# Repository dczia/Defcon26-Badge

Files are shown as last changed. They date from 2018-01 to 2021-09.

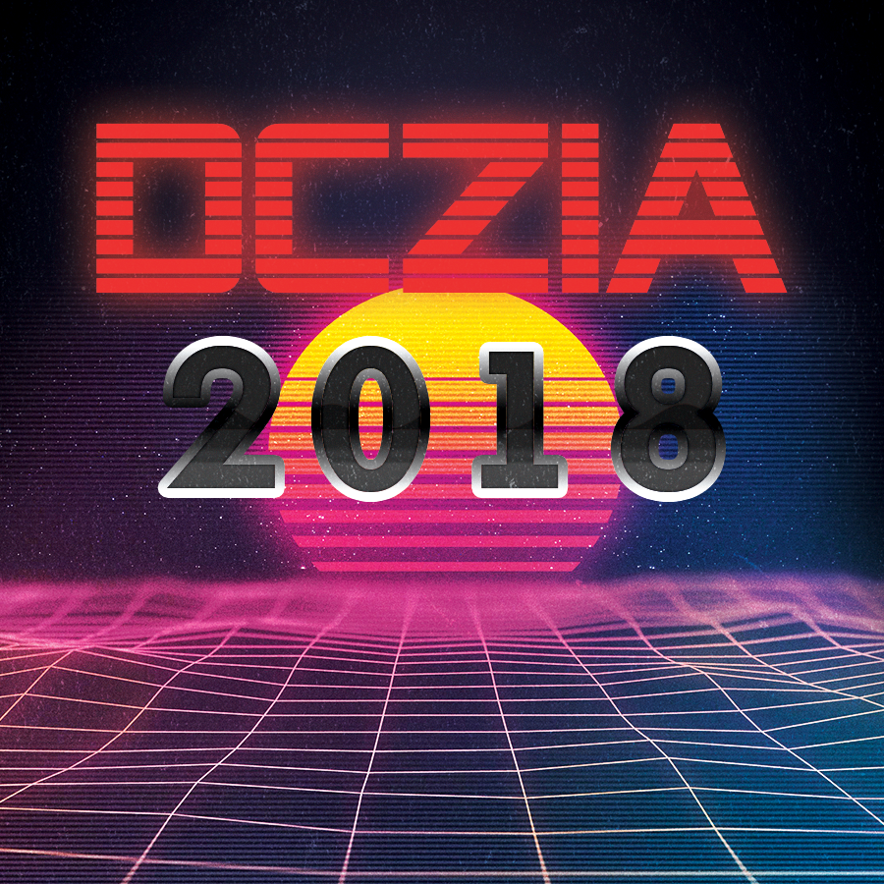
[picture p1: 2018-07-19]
Images/DCZia Sticker 3.png

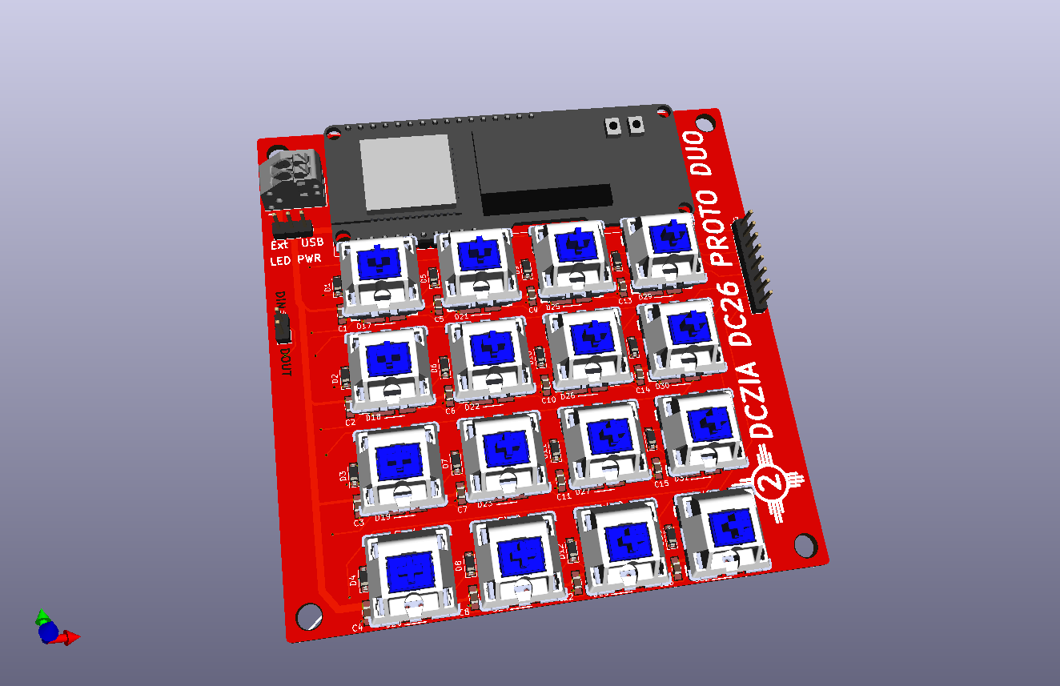
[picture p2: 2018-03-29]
Hardware/KeyGridBadge/images/Generated/KeyGridTest2_Front.png

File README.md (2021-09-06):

# ＤＣＺＩＡ ２０１８

```
 ___   ___ _____        ___ __  _ ___
|   \ / __|_  (_)__ _  |_  )  \/ ( _ )
| |) | (__ / /| / _` |  / / () | / _ \
|___/ \___/___|_\__,_| /___\__/|_\___/

 _________
| DCZ ■■ ⧻|
| □ □ □ □ |
| □ □ □ □ |
| □ □ □ □ |
|_□_□_□_□_|

```
**News**
September 2021
* Added new pre built binary file of the badge firmware with bug fixes for the boot loop issue. (Thanks to Aask for the guidance!)
* Updated final software readme and this readme.

August 2018
* FINAL INO is up use that for use with the final board.  
* ProtoDos is frozen for now. Library changes + board layout changes mean Final and Dos aren't really interchangable.

July 2018 Update 2
* ProtoDos code updated with BLE Code working and advertising to DC26 with 0X5050 Manufacturing ID
* Some ProtoDos code cleanup 

June 2018 Update
* Final board revision in the works. Expecting proto tres boards soon.
* Possibly switching OLED Libraries to U8G2 (https://github.com/olikraus/u8g2)
* Screen will likely be a 0.91" 128x32pixel OLED ala https://www.aliexpress.com/item/0-91-Inch-128x32-IIC-I2C-Blue-OLED-LCD-Display-DIY-Module-SSD1306-Driver-IC-DC/32793415973.html
	
May 2018  Update
* Proto Tres Board revision has begun.
* Please write down your ideas for lighting / BLE in the Google Doc for badge development.

March 2018 Update
* Proto Dos boards are in, working, and off to Lithochasm for redistribution with the keys

Feb 2018 Update
* Dev boards have been made by Hamster. He identified an issue with the footprint of the leds, and is working on a fix.
* Clear keycaps have begun printing by Litho. Switches and LED's for a dev board test have been ordered as well.
* Software developemt has not begun. 
* Goals for Feb, get dev boards up and in the hands of folks. 
* Ideas for software features
* Laynard Design

**What is the DCZia 2018 Badge**

This year we want to keep up with the tradition of our past badge which contained mechanical keyswitches on it to give it a retro look and feel. We decided on a 4x4 grid of mechanical keyswitches with an rgb led underneath and transparent keycaps to make an interactive display of sorts.

We also will be adding a small oled at the top center of the badge for more ovbious visual output. Board will be powered by an ESP32 and will talk BTLE and possibly Wi-Fi if we can find something cool to do with it.

Defcon2018 Style Guide: https://defcon.org/html/defcon-26/dc-26-theme.html

**Technical Notes**
* ESP32 Microcontroller
* SSD1306 OLED Screen
* Gatreon Blue Keyswitches
* Neopixel Mini RGB LEDs
* 3x AA power or USB power
* Shitty / Minibadge Addons supported

**DevKit Setup Instructions**

- Follow the [ESP32 Setup Instructions](https://github.com/espressif/arduino-esp32#installation-instructions) to get the latest board version. (NOTE: This is required to use BLE as there are recent updates)
- Compile and upload to your Proto-Dos board
- Enjoy all the fun menu settings, light show and BLE experience. 

To Test: 
- Use Nordic's nRF utility for the phone. 
- Review #badgelife's doc for BLE communication.  Compare to last year's badge to see the correct manufacturer ID and appearance.

#dczia

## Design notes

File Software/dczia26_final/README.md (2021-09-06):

# dczia26_final

This is it.

## Overview
DC Zia 26 - 2018 Final Build Out.
This should cover what is required for building and loading the sketch onto the DC Zia badge.
You can build the firmware using the arduino .ino sketch, or we now have a binay file that can be uploaded using something like esptool (https://diyprojects.io/esp-easy-flash-firmware-esptool-py-esp8266/)

### Required Libraries
- Espressif ESP32 - [ESP32 Setup Instructions](https://github.com/espressif/arduino-esp32#installation-instructions)
- NeopixelBus
- arduinoFFT
- Adafruit SSD1306 OLED Library
- Adafruit GDX Library
- Neopixel BUS Library
- Keypad (http://playground.arduino.cc/Code/Keypad)

### Build Instructions
Make sure you're running a recent version of Arduino Studio. 
Follow the instructions for installing the Espressif ESP32 boards via the board manager at ([ESP32 Setup Instructions](https://github.com/espressif/arduino-esp32#installation-instructions)).

Open `dczia_final.ino` in Arduino Studio.
Select the correct board:
  - TOOLS -> Board -> ESP 32 Dev Module
Select the connected COM port (should be autodetected).
Compile the sketch using the checkmark.
Upload the sketch to the board.
Enjoy the lightshow.

### Usage of the Badge
The Board will boot into a default light mode. Press and hold the bottom right key to exit the current mode and goto the main menu.
The top 9 buttons each will activate a different mode.
Press and hold the bottom right key to exit the current mode.

### Troubleshooting
- Fails to compile
  - Double check that Espressif ESP32 is installed correctly
  - Review all required libraries and make sure they're installed
  - Review errors to identify if it is a board issue vs a library issue.
- Fails to upload
  - Double check to make sure Espressif python tools were fully configured.
  - Make sure the badge is connected and on (reconnect with badge switched to ON without batteries)
- Display issues
  - Make sure you're using Adafruit libraries and it is configured for `128x32`

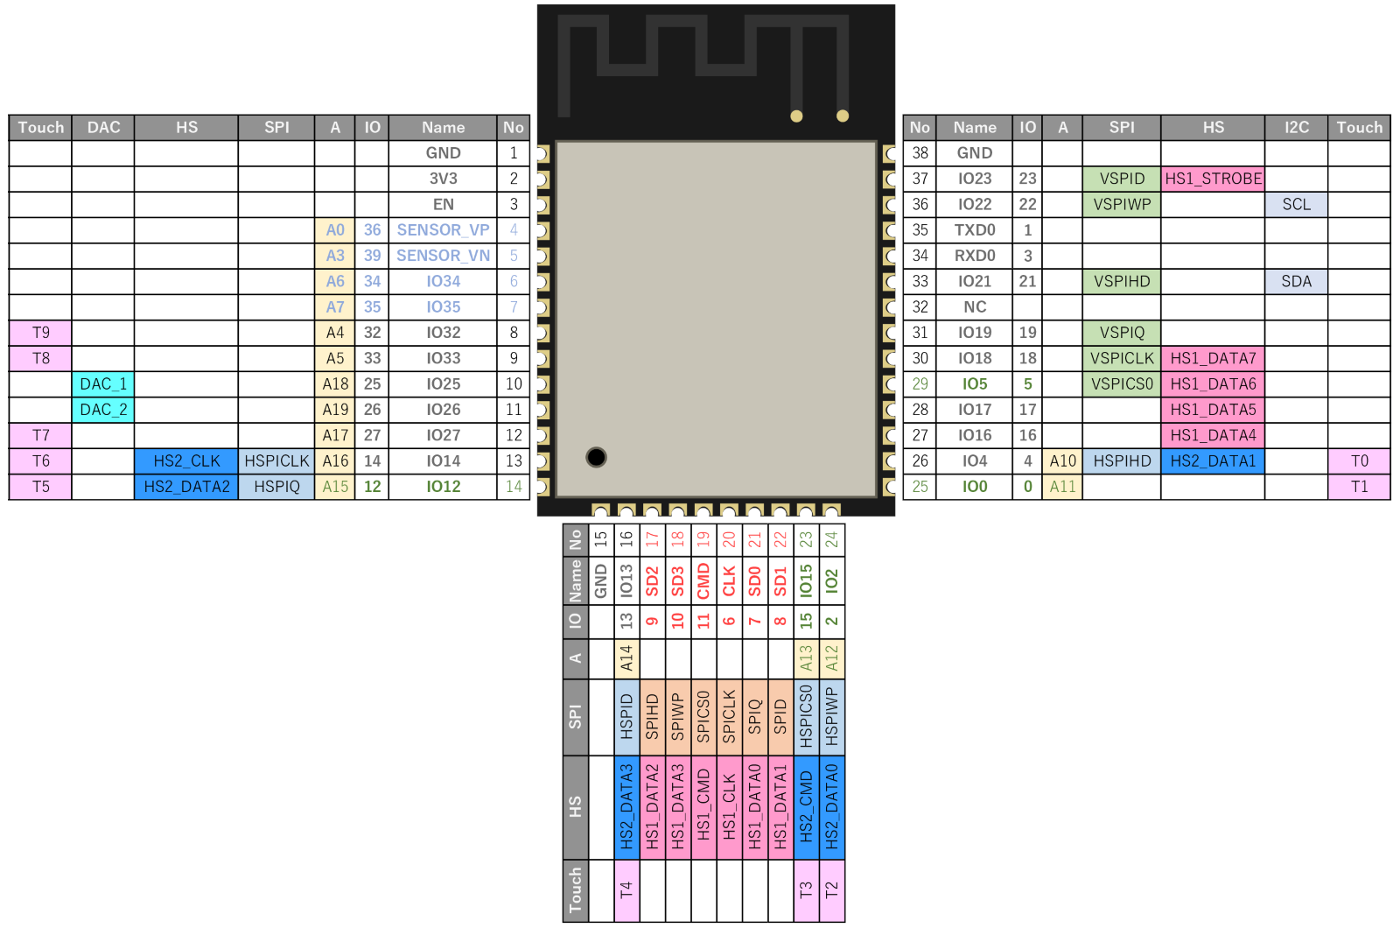
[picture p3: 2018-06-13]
Hardware/esp32_info/esp-wroom-32_pinout_01.png

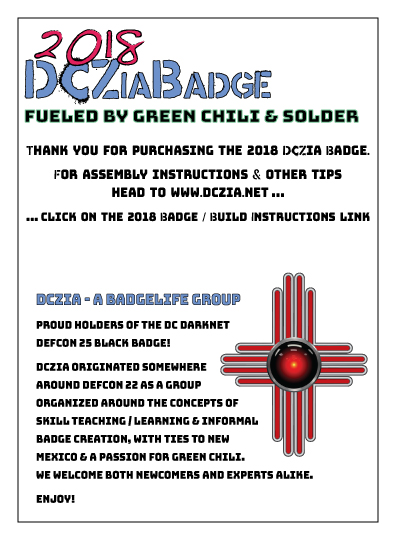
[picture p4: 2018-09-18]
Images/2018CardBack.jpg

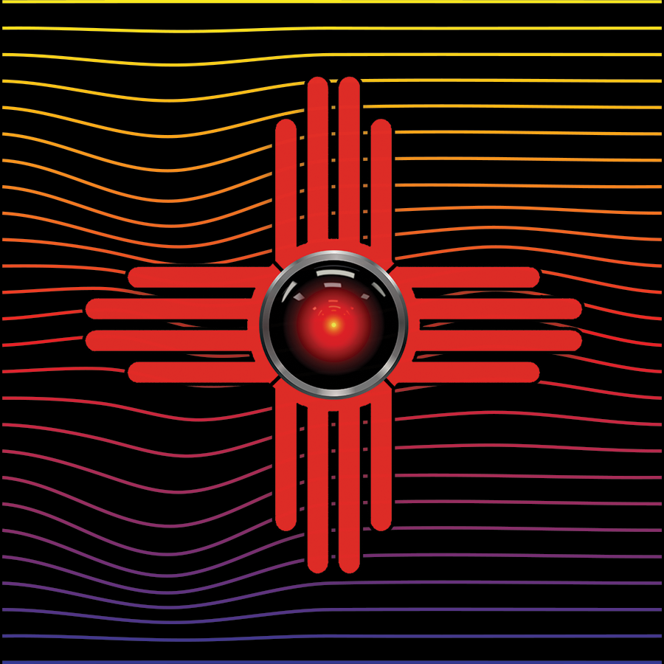
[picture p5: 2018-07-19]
Images/DCZia Line.png

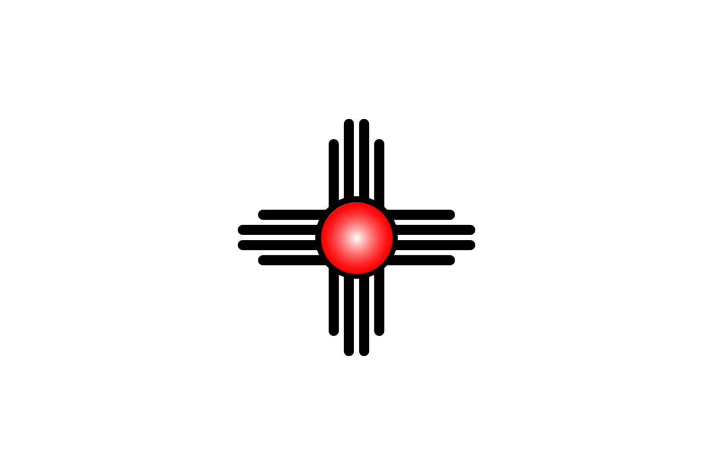
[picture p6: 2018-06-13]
Images/DCZia Main.png

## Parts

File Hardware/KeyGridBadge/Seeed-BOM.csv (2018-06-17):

Designator | Manufacturer Part Number | Quantity
C1,C2,C3,C4,C5,C6,C7,C8,C9,C10,C11,C12,C13,C14,C15,C16,C20,C22,C23,C24,C25,C26,C27,C28 | 302010165 | 24
C18,C19 | 302010007 | 2
D17,D18,D19,D20,D21,D22,D23,D24,D25,D26,D27,D28,D29,D30,D31,D32 | 304010007 | 16
D33 | 304020034 | 1
J1 | 320010003 | 1
J3 | 320090008 | 1
Q2 | 305030026 | 1
R3,R4 | 301012162 | 2
R5,R6,R7,R8 | 301010319 | 4
R9,R10,R11,R12,R13 | 301012152 | 5

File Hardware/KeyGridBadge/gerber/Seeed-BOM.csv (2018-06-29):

Designator | Manufacturer Part Number | Quantity
C1,C2,C3,C4,C5,C6,C7,C8,C9,C10,C11,C12,C13,C14,C15,C16,C20,C22,C23,C24,C25,C26,C27,C28 | 302010165 | 24
C18,C19 | 302010007 | 2
C21 | 302010158 | 1
C25,C30 | 302010171 | 2
D1,D17,D18,D19,D20,D21,D22,D23,D24,D25,D26,D27,D28,D29,D30,D31,D32,D33 | 304020034 | 18
J1 | 320010003 | 1
J3 | 320090008 | 1
Q2 | 305030026 | 1
R3,R4 | 301012162 | 2
R5,R6,R7,R8 | 301010319 | 4
R9,R10,R11,R12,R13 | 301012152 | 5

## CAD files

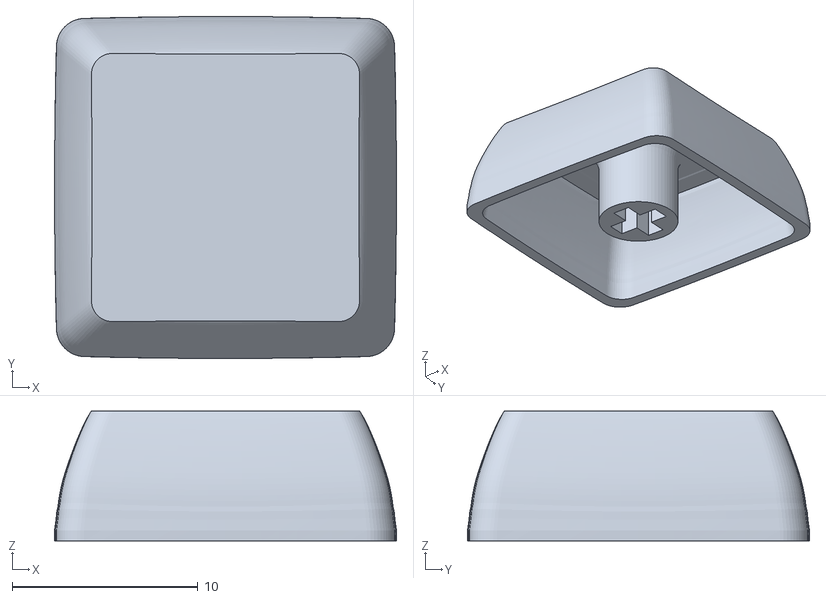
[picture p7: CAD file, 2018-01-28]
Hardware/Keycaps/Cherry_MX_Keycap_Flat_Top_WNA.stl
18.4 x 18.4 x 6.99

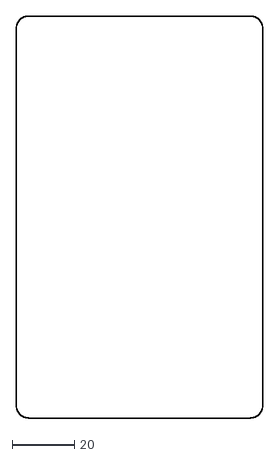
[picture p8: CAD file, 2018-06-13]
Hardware/KeyGridBadge/images/Generated/dczia-defcon26.dxf
79.1 x 129.0

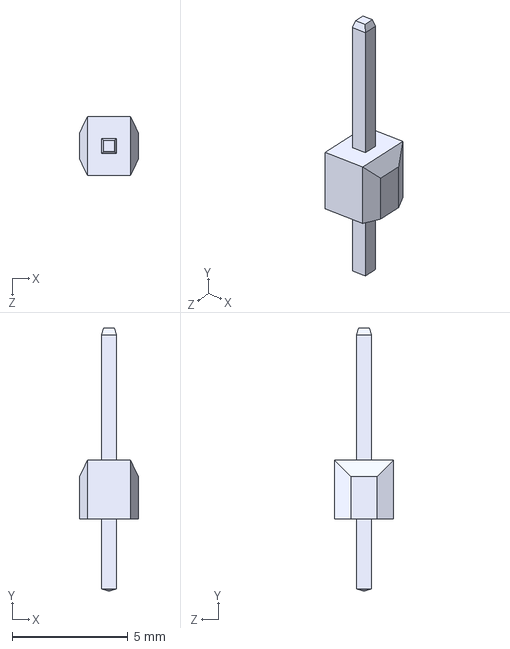
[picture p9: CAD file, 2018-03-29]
Hardware/KeyGridBadge/3d/male header.STEP
2.54 x 11.3 x 2.54 mm

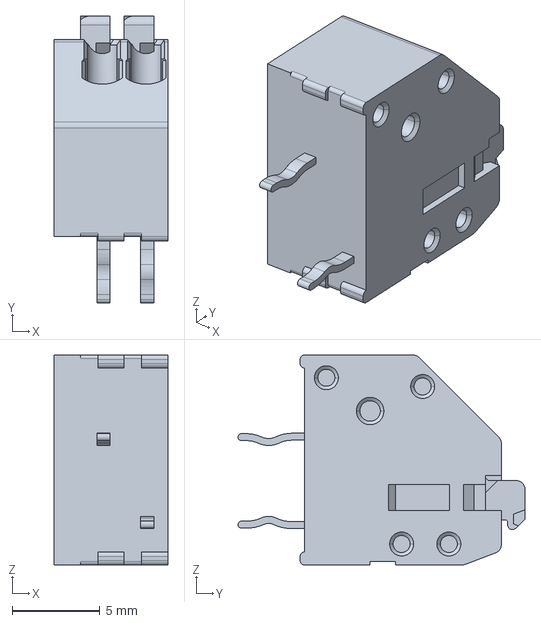
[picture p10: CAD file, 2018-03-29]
Hardware/KeyGridBadge/3d/c-1-2834021-2-1-3d.step
6.50 x 16.4 x 12.0 mm

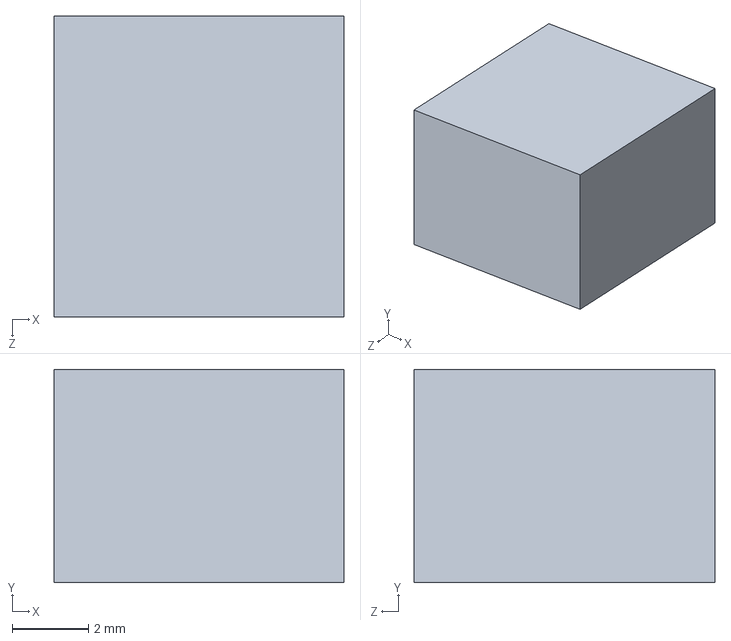
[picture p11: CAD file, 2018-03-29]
Hardware/KeyGridBadge/3d/Power.sldprt
7.60 x 5.60 x 7.90 mm

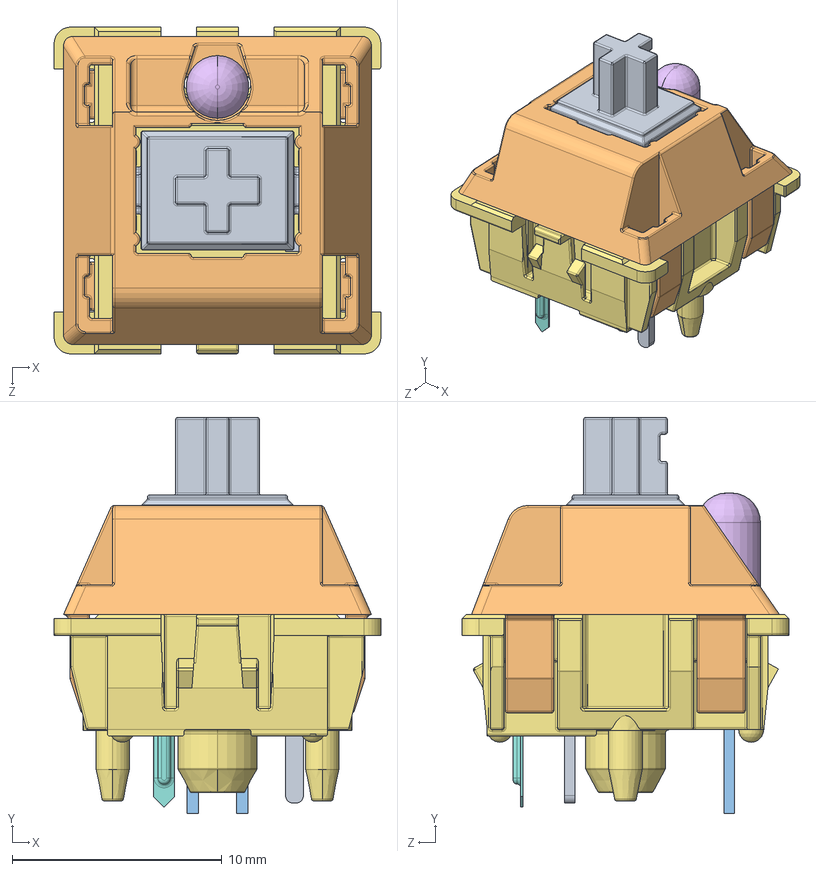
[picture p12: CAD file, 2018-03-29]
Hardware/KeyGridBadge/3d/MX.STEP
15.6 x 18.9 x 15.6 mm
MX ? ?? x 2
MX? ??LED
MX? ?? ??___
??___

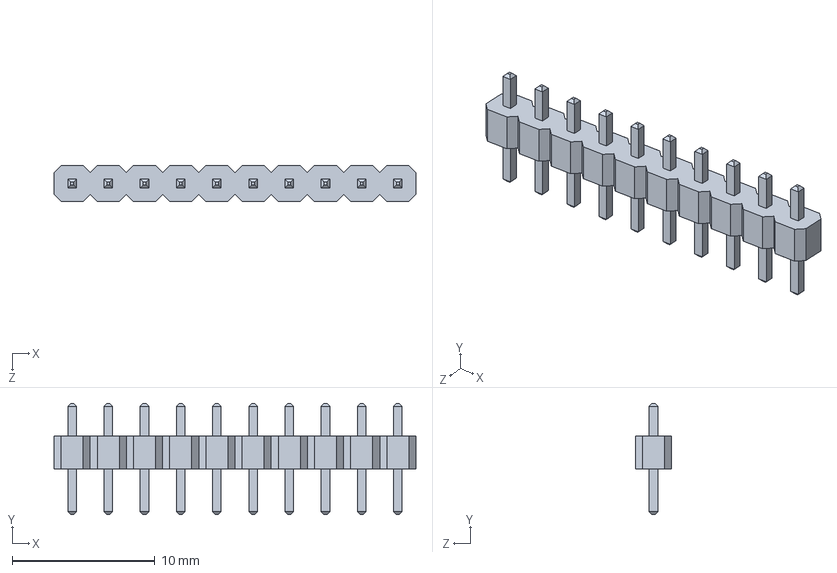
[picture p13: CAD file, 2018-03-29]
Hardware/KeyGridBadge/3d/Header 10 Pin.sldprt
25.4 x 7.80 x 2.54 mm

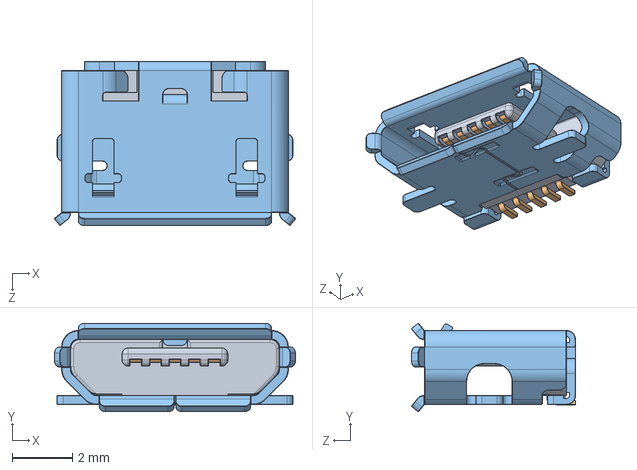
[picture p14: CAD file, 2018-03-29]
Hardware/KeyGridBadge/3d/micro USB.STEP
7.97 x 2.92 x 5.43 mm
micro usb02
micro usb

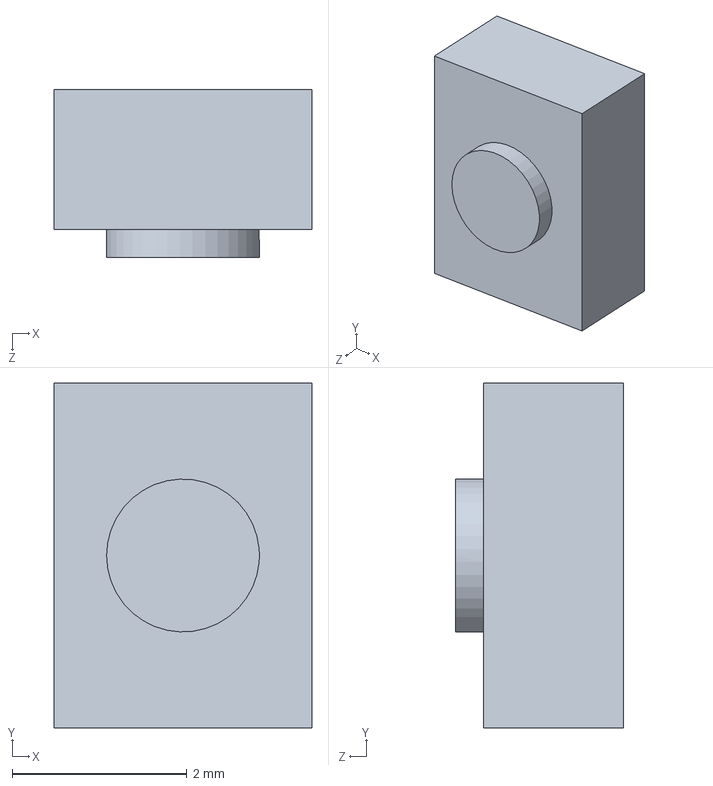
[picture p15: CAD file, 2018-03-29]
Hardware/KeyGridBadge/3d/Button.sldprt
2.95 x 3.95 x 1.92 mm

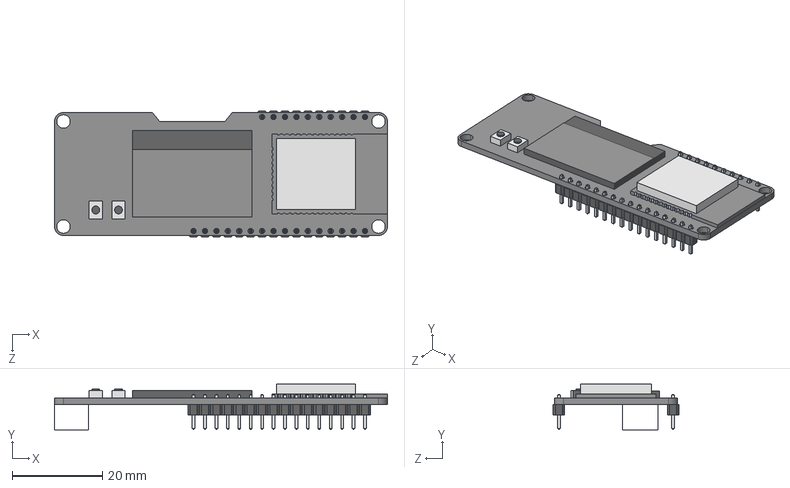
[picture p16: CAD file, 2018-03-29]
Hardware/KeyGridBadge/3d/Wemos.STEP
74.0 x 10.1 x 27.9 mm
WemosBoard^Wemos
ESP32
Header 10 Pin
Header 16 Pin^Wemos
OLED^Wemos
Button x 2
Power

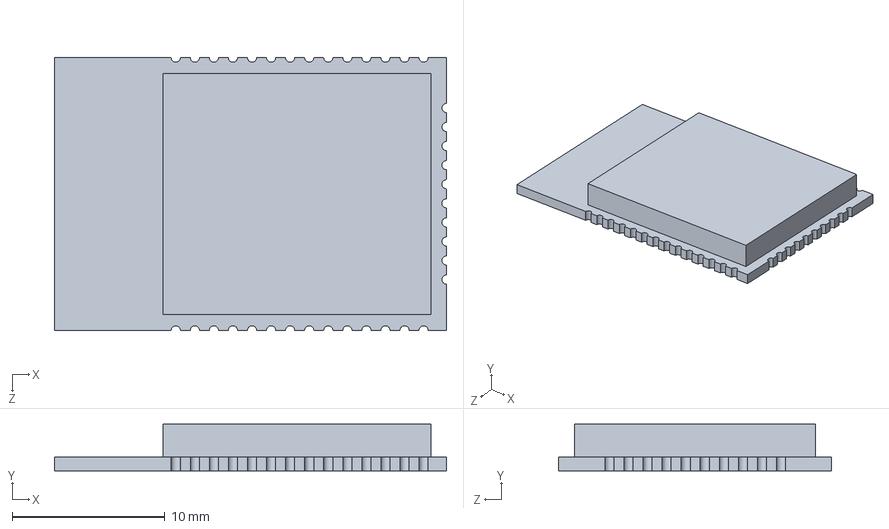
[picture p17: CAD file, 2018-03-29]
Hardware/KeyGridBadge/3d/ESP32.sldprt
25.7 x 3.05 x 17.9 mm

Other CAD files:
Hardware/KeyGridBadge/3d/micro usb02.sldprt
Hardware/KeyGridBadge/3d/MX_ __LED.sldprt
Hardware/KeyGridBadge/3d/MX _ ___2.sldprt
Hardware/KeyGridBadge/3d/Header 1 Pin.SLDPRT
Hardware/KeyGridBadge/3d/micro usb shield.sldprt
Hardware/KeyGridBadge/3d/micro usb insert.sldprt
Hardware/KeyGridBadge/3d/Imported.sldprt
Hardware/KeyGridBadge/3d/MX _ __.sldprt
Hardware/KeyGridBadge/3d/MX.SLDASM
Hardware/KeyGridBadge/3d/MX_ __ _____.sldprt
Hardware/KeyGridBadge/3d/Wemos.SLDASM
Hardware/KeyGridBadge/3d/male header.SLDPRT
Hardware/KeyGridBadge/3d/micro USB.SLDASM
Hardware/KeyGridBadge/3d/micro usb.sldprt

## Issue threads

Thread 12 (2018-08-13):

Boot Loop / Stuck on "Initalization" Screen

lithochasm, 2018-08-13:
We have a possible fix for this by turning off some services at boot and disabling the brownout detector. Will push new firmware "soon"

Aask42, 2019-06-02:
In testing I've found version 1.2.4 of Arduino1306.h reduces the occurrence of this bug. On later versions of the library the screen ends up not even coming on sometimes. With this version of the library it will glitch on first boot, but then seems to work fine afterwords.

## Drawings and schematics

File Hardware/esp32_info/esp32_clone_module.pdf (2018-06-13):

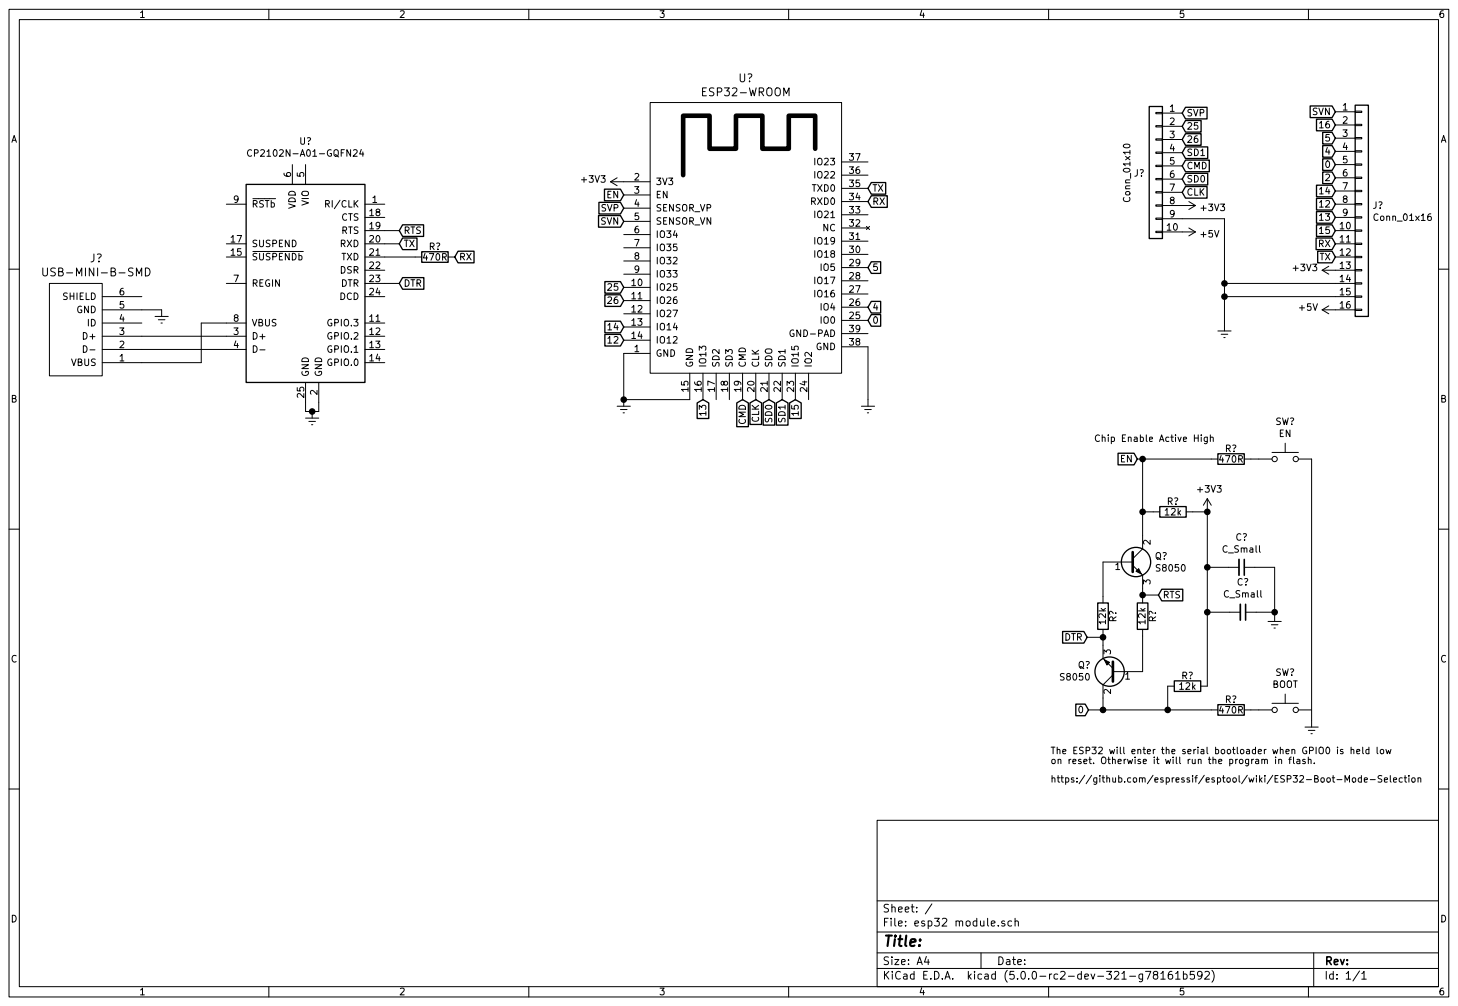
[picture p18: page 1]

6 REGIN 7 VBUS 8 RSTb 9 U? CP2102N-A01-GQFN24 VBUS 1 D- 2 D+ 3

2 RXD 20 TXD 21 DSR 22 DTR 23 DCD 24 GND 25 D+ 3 D- 4 VIO

The ESP32 will enter the serial bootloader when GPIO0 is held low on reset. Otherwise it will run the program in flash.

https://github.com/espressif/esptool/wiki/ESP32-Boot-Mode-Selection

File: esp32 module.sch Sheet: /
Id: 1/1 Title:

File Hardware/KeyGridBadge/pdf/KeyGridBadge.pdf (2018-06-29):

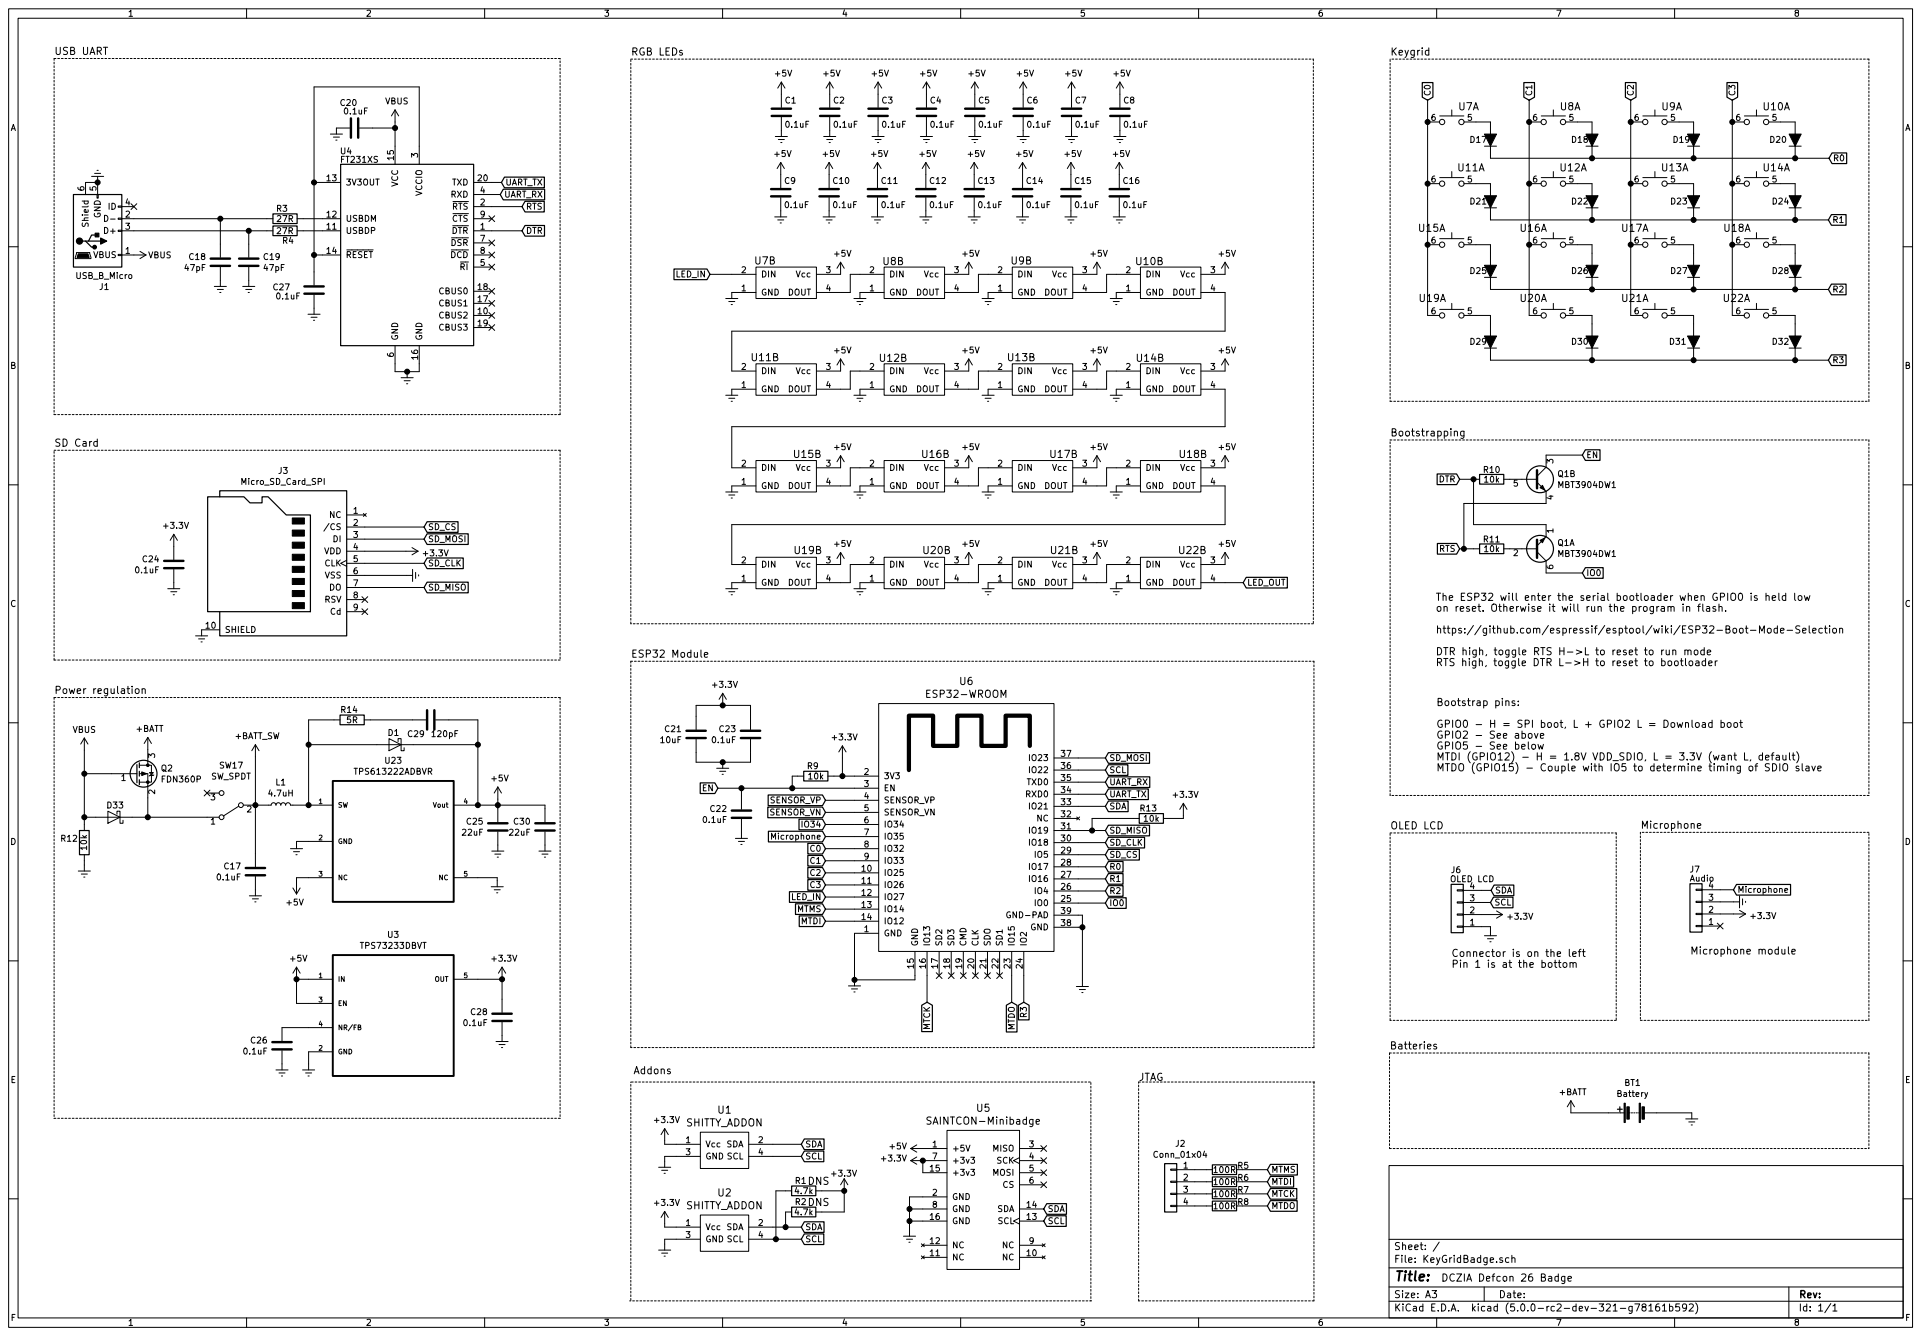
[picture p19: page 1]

6 DSR 7 DCD 8 CTS 9 U4FT231XS DTR

IO0 EN The ESP32 will enter the serial bootloader when GPIO0 is held low

on reset. Otherwise it will run the program in flash.
https://github.com/espressif/esptool/wiki/ESP32-Boot-Mode-Selection
DTR high, toggle RTS H->L to reset to run mode
RTS high, toggle DTR L->H to reset to bootloader

Bootstrap pins:
GPIO0 - H = SPI boot, L + GPIO2 L = Download boot
GPIO2 - See above
GPIO5 - See below
MTDI (GPIO12) - H = 1.8V VDD_SDIO, L = 3.3V (want L, default)
MTDO (GPIO15) - Couple with IO5 to determine timing of SDIO slave

File: KeyGridBadge.sch Sheet: /

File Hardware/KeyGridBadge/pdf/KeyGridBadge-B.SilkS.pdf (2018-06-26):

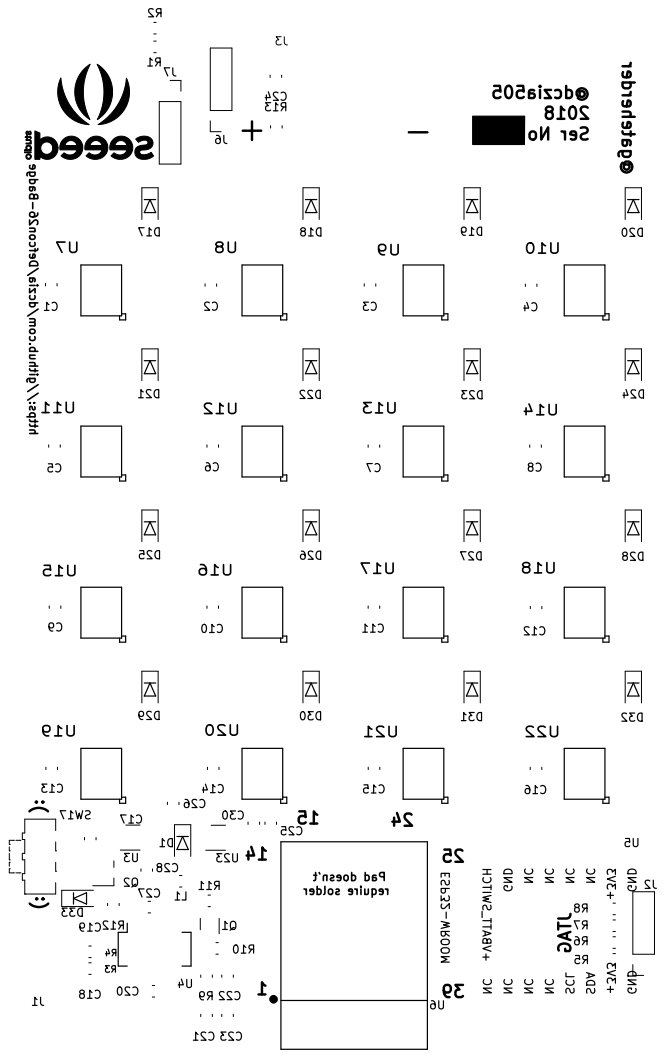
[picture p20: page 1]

Pad doesn't require solder @gateherder https://github.com/dczia/Defcon26-Badge :) :( 39

J6 SW17 C17 C18 C19 C25 C26 C28 D33 U3 U5 NCNCNCNCSCL SDA +3V3 GND GND +3V3NCNCNCNC GND +VBATT_SWITCH

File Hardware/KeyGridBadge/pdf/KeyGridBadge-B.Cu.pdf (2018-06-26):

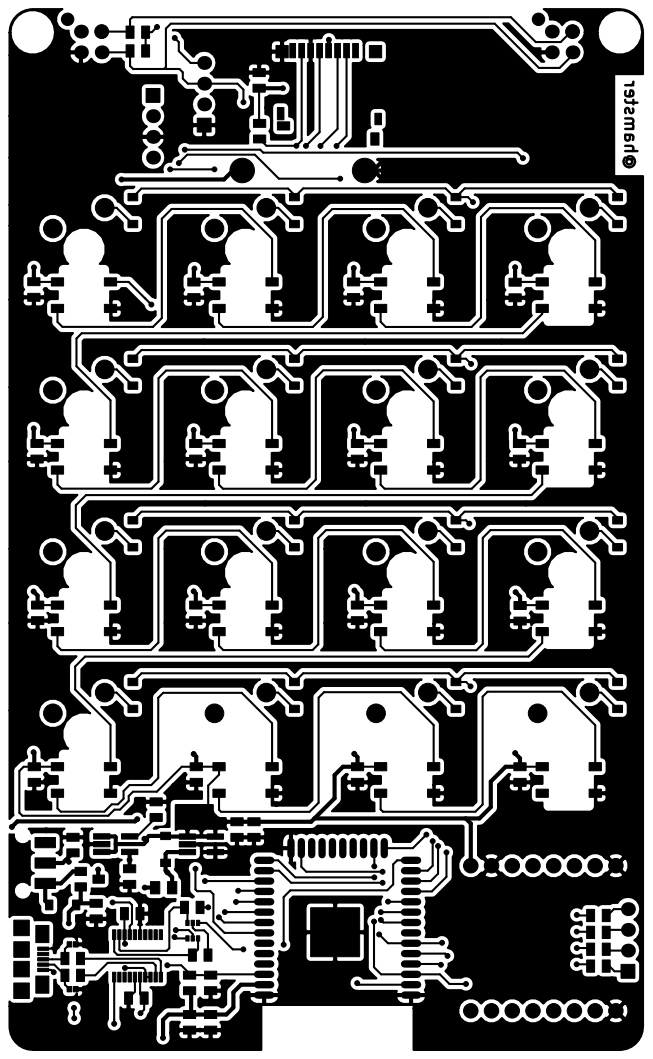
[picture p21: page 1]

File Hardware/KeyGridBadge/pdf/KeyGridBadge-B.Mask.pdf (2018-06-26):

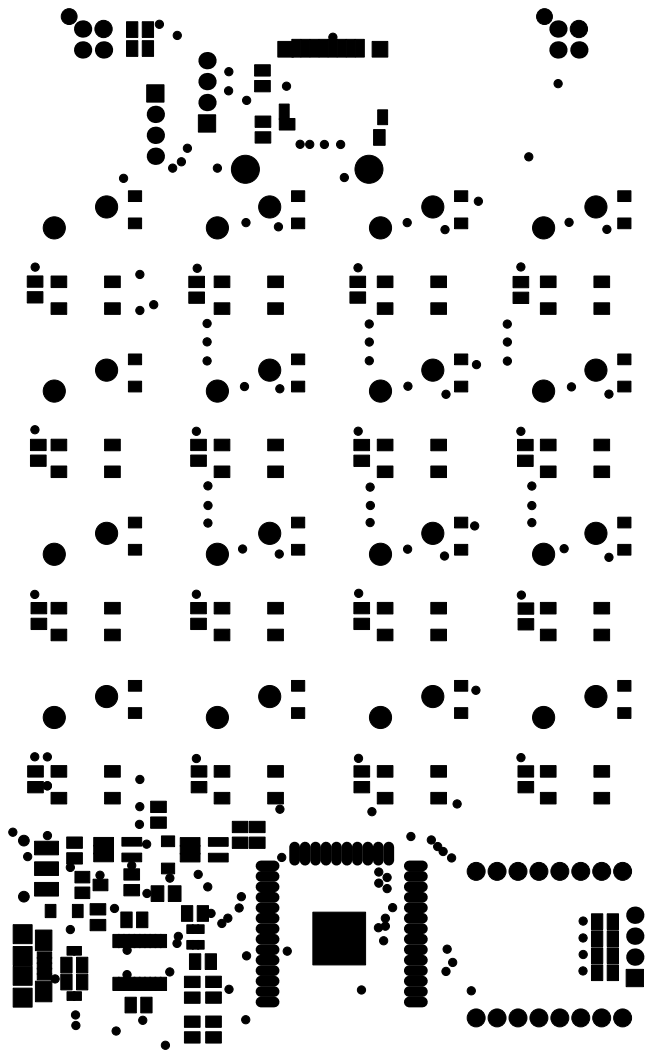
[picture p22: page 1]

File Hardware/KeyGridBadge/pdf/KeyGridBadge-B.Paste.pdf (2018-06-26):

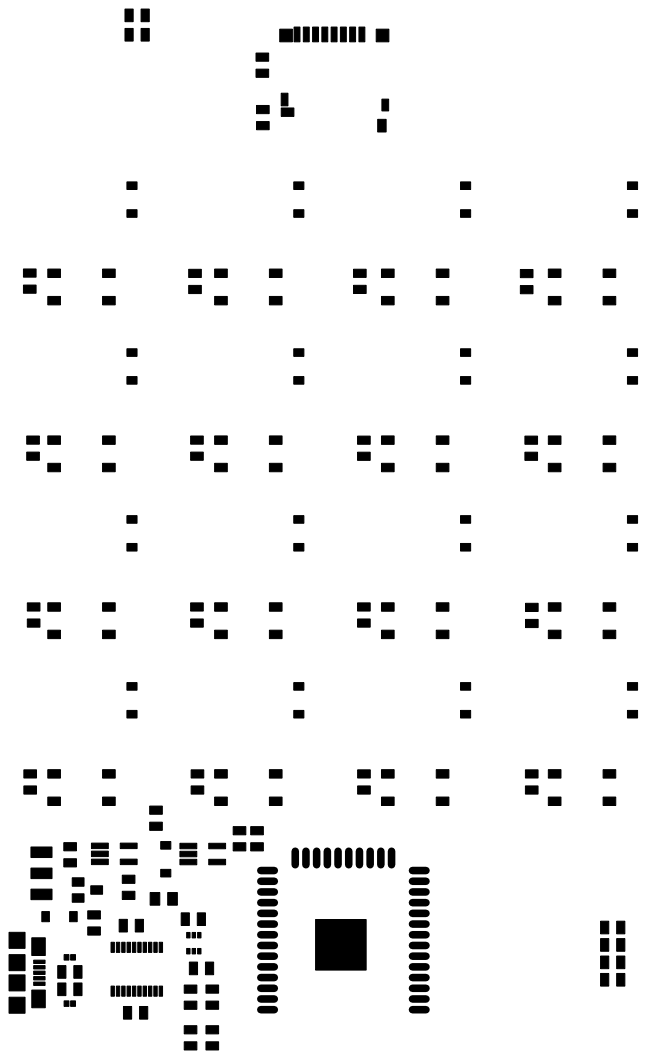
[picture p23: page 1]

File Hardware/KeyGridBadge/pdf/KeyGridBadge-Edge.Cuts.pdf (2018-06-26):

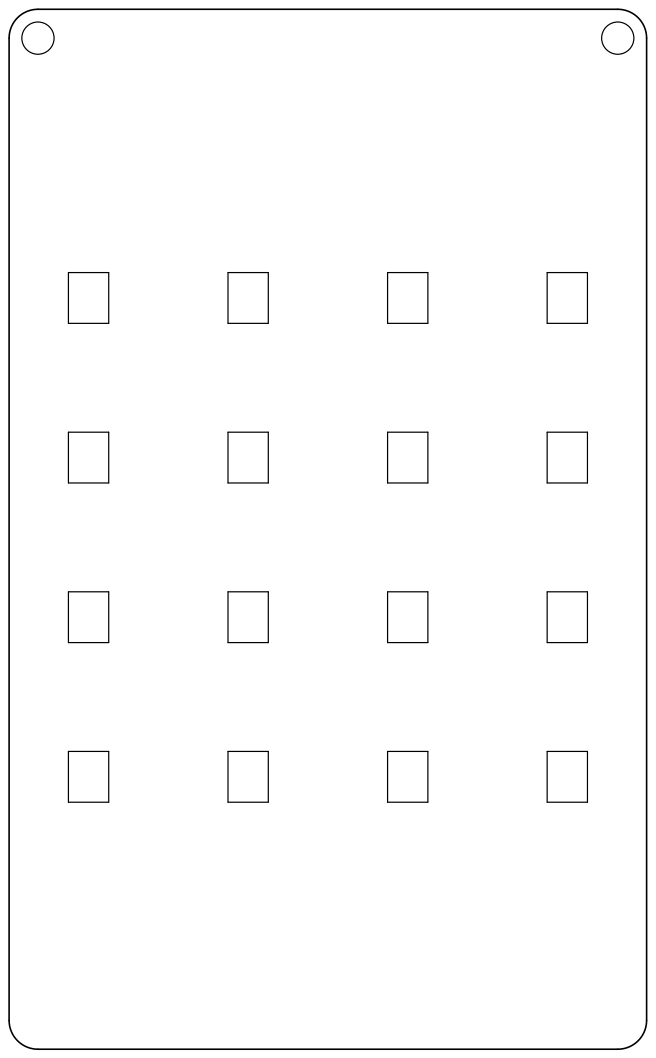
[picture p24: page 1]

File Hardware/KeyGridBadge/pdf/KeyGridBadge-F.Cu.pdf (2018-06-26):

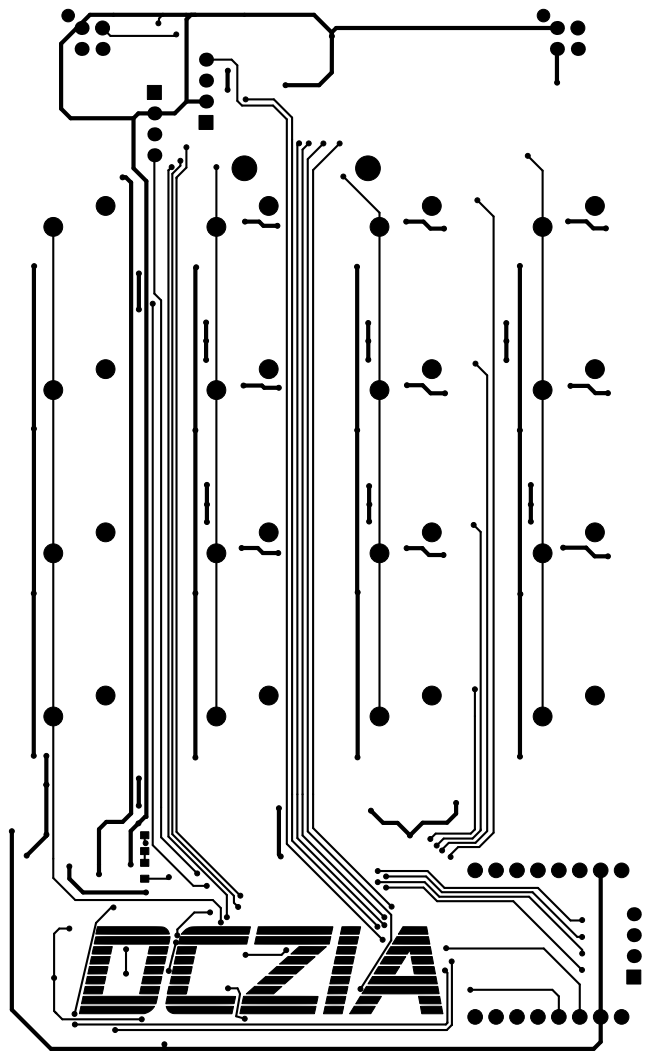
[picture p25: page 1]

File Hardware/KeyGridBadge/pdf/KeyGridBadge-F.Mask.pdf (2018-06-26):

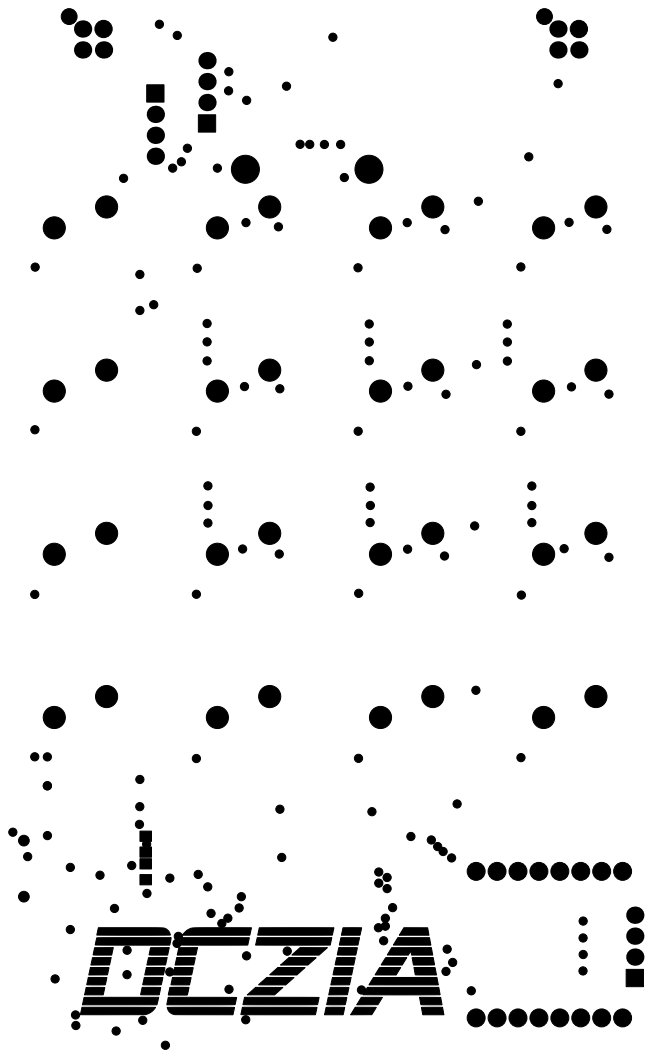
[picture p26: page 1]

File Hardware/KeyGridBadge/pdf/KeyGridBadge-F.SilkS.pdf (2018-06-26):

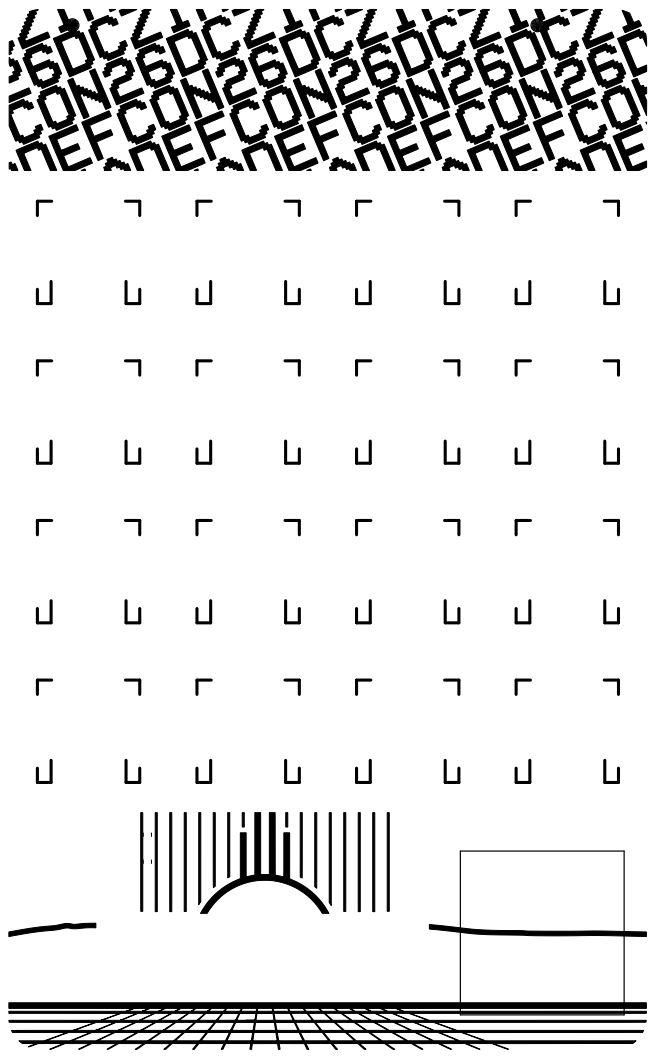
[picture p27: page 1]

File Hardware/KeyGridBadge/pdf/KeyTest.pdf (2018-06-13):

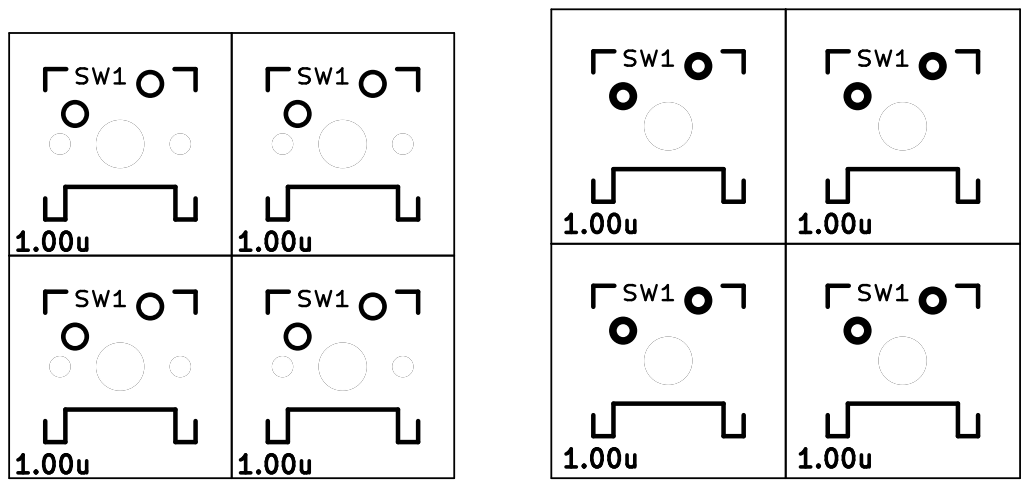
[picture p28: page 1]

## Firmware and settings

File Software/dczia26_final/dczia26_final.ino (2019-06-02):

// dczia 2019 firmware for DCZia26 Badge
// combines all major hardware aspects (led, oled, keypad, ble, mic)

// split into functional regions
#include "Key.h" // This was referred to as dczia.h previously
#include "dczia26_keypad.h"
#include "dczia26_led.h"
#include "dczia26_oled.h"
#include "dczia26_ble.h"
#include "dczia26_sd.h"
#include "arduinoFFT.h" // Standard Arduino FFT library 

arduinoFFT FFT = arduinoFFT(); // Create FFT object

#define COLOR_GREEN HslColor(120.0 / 360.0, 1.0, 0.10)
#define COLOR_BLUE HslColor(240.0 / 360.0, 1.0, 0.05)
#define COLOR_TEAL HslColor(175.0 / 360.0, 1.0, 0.10)
#define COLOR_VIOLET HslColor(300.0 / 360.0, 1.0, 0.10)
#define COLOR_RED HslColor(360.0 / 360.0, 1.0, 0.10)
#define COLOR_YELLOW HslColor(60.0 / 360.0, 1.0, 0.10)
#define COLOR_PINK HslColor(335.0 / 360.0, 1.0, 0.10)

// Initilazie the LED decay for animating the LEDs to the mic input
int decayLED_a = 0;
int decayLED_b = 0;
int decayLED_c = 0;
int decayLED_d = 0;

// Global variables
Adafruit_SSD1306   *oled = NULL; // uses v3.xx from "esp8266 and esp32 oled driver for ssd1306 display" (https://github.com/ThingPulse/esp8266-oled-ssd1306)
Keypad             *keys = NULL; // currently customized and included within project (will update to forked lib later)
hw_timer_t         *timer = NULL;

volatile char lastKey = NO_KEY;

char getLastKey(void);
void displayUpdate(std::string message);
void runDefaultAnimations(void);

void IRAM_ATTR onTimer() {
  char tempKey = keys->getKey();
  if(tempKey != NO_KEY){
    lastKey = tempKey;
  }
}

// Set up the mic for audio capture
#define MIC1_PIN 35               // Microphone is attached to Trinket GPIO #2/Gemma D2 (A1)
#define DC_OFFSET 0               // DC offset in mic signal - if unusure, leave 0
#define NOISE 30                  // Noise/hum/interference in mic signal
#define SAMPLES 256               // Length of buffer for dynamic level adjustment
#define SAMPLING_FREQUENCY 40000  // Hz, must be 40000 or less due to ADC conversion time. Determines maximum frequency that can be analysed by the FFT Fmax=sampleF/2.
#define amplitude 100             // Depending on your audio source level, you may need to increase this value

unsigned int sampling_period_us;
unsigned long microseconds;
byte peak[] = {0,0,0,0,0,0,0};
double vReal[SAMPLES];
double vImag[SAMPLES];
unsigned long newTime, oldTime;

int pointsPerSecond=100;
int captureMinutes = 60;
int delayMS = 1000/pointsPerSecond;
int datapoints=pointsPerSecond * captureMinutes * 60;
int curIdx=0;

// Setup the board
void setup(void) {
  // init system debug output
  Serial.begin(115200);

  // Call class constructors
  Serial.println("Constructing...");
  keys = keypad_setup();
  delay(1);

  //Setup LEDS
  Serial.println("Set up LEDs...");
  strip.Begin();
  strip.Show();
  startupAnimation();
  strip.Show();

  // Setup the key scan interrupt
  Serial.println("Set up \"Key Scan\"...");
  timer = timerBegin(0, 80, true);
  timerAttachInterrupt(timer, &onTimer, true);
  timerAlarmWrite(timer, 10000, true);
  timerAlarmEnable(timer);

  // Setup the OLED
  Serial.println("Set up OLED...");
  oled = oled_setup();

  // Setup the bluetooth
  // COMMENT THIS OUT if your board gets stuck in a bootloop, or add a 100uF capacitor to C21 (boards sold on Tindie alreay have this fix)
  Serial.println("Set up BLE...");
  ble_setup();

  // call welcome screen (once)
  Serial.println("Display welcome screen...");
  oled_welcome(oled);

  // Set a random seed
  Serial.println("Set a random seed...");
  SetRandomSeed();

  // Detect and setup a SD card
  Serial.println("Check for SD card...");
  SDSetup(oled);

  // Set up Microphone
  Serial.println("Set up Microphone (MAX4466 on J7)...");
  sampling_period_us = round(1000000 * (1.0 / SAMPLING_FREQUENCY));

  // done with init fuction
  Serial.println("Done With Setup!");

}

// in arduino world, "loop()" is called over and over and over and ...
// you get the idea... we don't need to "while(1)" ourselves...
void loop(void) {

  // Store what mode we're currently in
  static char mode = '1';
  static char oldMode = '1';

  // Determine if we've changed the mode.  Use this to initialize the animations
  static boolean newmode = true;

  // Is menu mode selected?
  if (keys->getState('D') == HOLD) {
      // User wants to select a new mode, jump to menu mode
      mode = 'D';
  }

  if(oldMode != mode){
    Serial.printf("Mode is %c (%d)\r\n", mode, mode);
    oldMode = mode;
  }

  // Run the code associated with the particular command
  switch (mode) {
    case '1': // Reserved for Light Mode
    case '8': // Reserved for Function Mode
    case '9': // Reserved for Function Mode
    case '*': // Reserved for Funciton Mode
    default:
      // Set the mode message
      if(newmode){
        displayUpdate("Hold Bottom Right\nfor Main Menu");
        newmode = false;
      }
      runDefaultAnimations();
      break;

    case 'D':
      {
        // Set the mode message
        if(newmode){
          displayUpdate("Menu");
          newmode = false;
        }
  
        // Swap modes to whatever the last key pressed was
        char key = getLastKey();
        if(key != NO_KEY){
          mode = key;
          newmode = true;
        }
  
        //Default Animation Loop
        if (animations.IsAnimating()) {
          // The normal loop just needs these two to run the active animations
          animations.UpdateAnimations();
          strip.Show();
        } else {
          // No animation runnning, start some
          FadeInFadeOutRinseRepeat(0.05f); // 0.0 = black, 0.25 is normal, 0.5 is bright
        }
      }
      break;

    //Light modes:
    //1, 2, 3, A
    //4, 5, 6, B
    case '2':
      // Set the mode message
      if(newmode){
        displayUpdate("Bright Rainbow");
        newmode = false;
      }

      //Default Animation Loop
      if (animations.IsAnimating()) {
        // The normal loop just needs these two to run the active animations
        animations.UpdateAnimations();
        strip.Show();
      } else {
        // No animation runnning, start some
        FadeInFadeOutRinseRepeat(.5f); // 0.0 = black, 0.25 is normal, 0.5 is bright
      }
      break;

    case 'B': {
      // Set the mode message
      if(newmode){
        displayUpdate("Pixel Picker");
        newmode = false;
      }

      if (keys->getState('D') != HOLD) {
        // Turn off any animations
        animations.StopAnimation(0);
        delay(1);

        // Get a copy of the keymap
        uint16_t map = 0;
        for(uint8_t i = 0; i < 4; i++){
          map |= ((keys->bitMap[i] & 0x0F) << (i * 4));
        }

        // Determine if a pixel needs to be on or off
        for(uint8_t i = 0; i < 16; i++){
          if((map >> i) & 0x01){
            // Key is down
            strip.SetPixelColor(i, COLOR_GREEN);
          }
          else{
            strip.SetPixelColor(i, COLOR_BLUE);
          }
        }
        
        strip.Show();
      }
      break;
    }

    case 'A':
      // Set the mode message
      if (newmode){
        displayUpdate("Connection Machine");
        animations.StopAnimation(0);
        newmode = false;
      }
      //Connection Machine animation
      if (animations.IsAnimating()) {
        animations.UpdateAnimations();
        strip.Show();
      } else {
        PickRandom(.3);
      }
      break;

    case '4':
      // Set the mode message
      if (newmode){
        displayUpdate("Random Mode");
        animations.StopAnimation(0);
        newmode = false;
      }
   
      if (animations.IsAnimating()) {
        animations.UpdateAnimations();
        strip.Show();
      } else {
        Random(.2);
      }
      break;

    case '5':
      // Set the mode message
      if (newmode){
        displayUpdate("Light Walk Mode");
        animations.StopAnimation(0);
        newmode = false;
      }
        
      if (animations.IsAnimating()) {
        animations.UpdateAnimations();
        strip.Show();
      } else {
        LightIteration(.3);
      }
      break;

    case '3':
      // Set the mode message
      if (newmode){
        displayUpdate("Party Mode");
        animations.StopAnimation(0);
        newmode = false;
      }
        
      if (animations.IsAnimating()) {
        animations.UpdateAnimations();
        strip.Show();
      } else {
        PartyMode(.1);
      }
      break;

    case '6':
      // Set the mode message
      if (newmode) {
        displayUpdate("Color Waves");
        animations.StopAnimation(0);
        newmode = false;
      } else {
        ColorWaves(.1);
      }
      break;
    case '7':
      // Enter real-time audio response mode ^_^
      if(curIdx < datapoints){
        // Read from the mic until you hit the max datapoints (set above)
        oled->clearDisplay();
        for (int i = 0; i < SAMPLES; i++) {
          newTime = micros()-oldTime;
          oldTime = newTime;
          vReal[i] = analogRead(MIC1_PIN); // A conversion takes about 1uS on an ESP32
          vImag[i] = 0;
          while (micros() < (newTime + sampling_period_us)) { /* do nothing to wait */ }
        }
        FFT.Windowing(vReal, SAMPLES, FFT_WIN_TYP_HAMMING, FFT_FORWARD);
        FFT.Compute(vReal, vImag, SAMPLES, FFT_FORWARD);
        FFT.ComplexToMagnitude(vReal, vImag, SAMPLES);
        
        oled->setTextSize(1);
        oled->setTextColor(WHITE);
        oled->setCursor(0,0);
        // Note, these are my best guesses for frequency to pitch assignment
        // oled->println(" A  B  C  D  E  F  G");
        oled->println("420Hz---Aask---840Hz");

        for (int i = 2; i < (SAMPLES/2); i++){ // Don't use sample 0 and only first SAMPLES/2 are usable. Each array eleement represents a frequency and its value the amplitude.
          if (vReal[i] > 2000) { // Add a crude noise filter, 10 x amplitude or more
            int dsize = vReal[i]/amplitude;
            int dsizeLED = vReal[i]/amplitude;
            
            int dmax = 52;
            if (dsize > dmax) dsize = dmax;
            if (dsizeLED > dmax) dsizeLED = dmax;
            
            double peak = FFT.MajorPeak(vReal, SAMPLES, SAMPLING_FREQUENCY);

            // Serial.println(peak);     //Print out what frequency is the most dominant.
            // Animate the OLED
            for(double p = 1; p <= 4; p += 1.0){ // ensure adding doubles and
              if (peak >= p*420.00 && peak < p*466.16) displayBand(0,(int)dsize); // A-range - 400ish Hz, around an A
              if (peak >= p*466.16 && peak < p*508.00) displayBand(1,(int)dsize); // B
              if (peak >= p*508.00 && peak < p*570.00) displayBand(2,(int)dsize); // C
              if (peak >= p*570.00 && peak < p*640.00) displayBand(3,(int)dsize); // D
              if (peak >= p*640.00 && peak < p*680.00) displayBand(4,(int)dsize); // E
              if (peak >= p*680.00 && peak < p*760.00) displayBand(5,(int)dsize); // F
              if (peak >= p*760.00 && peak < p*840.00) displayBand(6,(int)dsize); // G
            }
            // Animate the LEDs
            // Grid looks like:
            /*____band____
               3  2  1  0 |
               7  6  5  4 | DSize
              11 10  9  8 |
              15 14 13 12 |
            */
            Serial.print("DSizeLED");
            Serial.print(dsizeLED);
            if (dsizeLED > 23) {
              for(int i = 15; i >= 12; i--){
                if(strip.GetPixelColor(i) != COLOR_GREEN) {
                  strip.SetPixelColor(i, COLOR_GREEN);
                }
              }
              decayLED_d = 0;
              decayLED_c = 0;
              decayLED_b = 0;
              decayLED_a = 2;
            }
            if(dsizeLED > 30){
              for(int i = 11; i >= 8; i--){
                if(strip.GetPixelColor(i) != COLOR_TEAL) {
                  strip.SetPixelColor(i, COLOR_TEAL);
                }
              }
              decayLED_d = 0;
              decayLED_c = 0;
              decayLED_b = 2;
              decayLED_a = 4;
            }
            if(dsizeLED > 40){
              for(int i = 7; i >= 4; i--){
                if(strip.GetPixelColor(i) != COLOR_YELLOW) {
                  strip.SetPixelColor(i, COLOR_YELLOW);
                }
              }
              decayLED_d = 0;
              decayLED_c = 2;
              decayLED_b = 4;
              decayLED_a = 6;
            }
            if(dsizeLED > 47){
              for(int i = 3; i >= 0; i--){
                if(strip.GetPixelColor(i) != COLOR_RED) {
                  strip.SetPixelColor(i, COLOR_RED);
                }
              }
              decayLED_d = 2;
              decayLED_c = 4;
              decayLED_b = 6;
              decayLED_a = 8;
            }
            
          }
          for (byte band = 0; band <= 6; band++) {
            oled->drawFastHLine(18*band,64-peak[band],14,1);
          }
        }

        // Decay the peak
        if (millis()%4 == 0) {
          for (byte band = 0; band <= 6; band++) {
            if (peak[band] > 0) peak[band] -= 1;
          }
        } 

        oled->display();
        strip.Show();

        // Pixel Picker!
        if (keys->getState('D') != HOLD) {
          // Get a copy of the keymap
          uint16_t map = 0;
          for(uint8_t i = 0; i < 4; i++){
            map |= ((keys->bitMap[i] & 0x0F) << (i * 4));
          }
          // Determine if a pixel needs to be on or off
          for(uint8_t i = 0; i < 16; i++){
            if((map >> i) & 0x01){
              // Key is down
              if(12 <= i && i <= 15) {
                strip.SetPixelColor(i, COLOR_GREEN);
                decayLED_a = 8;
              }
              if(8 <= i && i <= 11) {
                strip.SetPixelColor(i, COLOR_TEAL);
                decayLED_b = 6;
              }
              if(4 <= i && i <= 7) {
                strip.SetPixelColor(i, COLOR_PINK);
                decayLED_c = 4;
              }
              if(0 <= i && i <= 3) {
                strip.SetPixelColor(i, COLOR_VIOLET);
                decayLED_d = 2;
              }
            }
          }
        }

        curIdx++;
        delay(delayMS);
        if(curIdx >= datapoints){
          Serial.println("Done collecting audio samples!");
          mode = 'D';
        }
      
      
      if(decayLED_a == 0){
        for(int i = 15; i >= 12; i--){
          if(strip.GetPixelColor(i) != COLOR_BLUE) {
            strip.SetPixelColor(i, COLOR_BLUE);
          }
        }
      }
      if(decayLED_b == 0){
        for(int i = 11; i >= 8; i--){
          if(strip.GetPixelColor(i) != COLOR_BLUE) {
            strip.SetPixelColor(i, COLOR_BLUE);
          }
        }
      }
      if(decayLED_c == 0){
        for(int i = 7; i >= 4; i--){
          if(strip.GetPixelColor(i) != COLOR_BLUE) {
            strip.SetPixelColor(i, COLOR_BLUE);
          }
        }
      }
      if(decayLED_d == 0){
        for(int i = 3; i >= 0; i--){
          if(strip.GetPixelColor(i) != COLOR_BLUE) {
            strip.SetPixelColor(i, COLOR_BLUE);
          }
        }
      }
      if(decayLED_a > 0) decayLED_a--;
      if(decayLED_b > 0) decayLED_b--;
      if(decayLED_c > 0) decayLED_c--;
      if(decayLED_d > 0) decayLED_d--;
      }
      break;
      
    case '#':
      // BLE Scanning project

      if (newmode) {
        displayUpdate("BLE Scanning");
        newmode = false;
        
        int bleResults[3];
        
        oled->clearDisplay();
        oled->setCursor(0, 0);
        oled->setTextSize(2);
        oled->println("Scanning..");
        oled->display();
        
        ble_scan_dczia(bleResults);
        
        oled->clearDisplay();
        oled->setTextSize(1);
        oled->setCursor(0, 0);
        oled->println("- BLE Scan Results -");
        oled->print("BLE Devices: ");
        oled->print(bleResults[2]);
        oled->print("\n");
        oled->print("Defcon26 Badges: ");
        oled->print(bleResults[0]);
        oled->print("\n");
        oled->print("DCZia Badges: ");
        oled->print(bleResults[1]);
        oled->display();
      }
      runDefaultAnimations();
      break;

    case 'C':
      oled_displaytest(oled);
      // go back to menu
      mode = 'D';
      break;

    case '0':
      // Credits
      if (newmode) {
        oled_displayCredits(oled);
        //Put it back on the main menu...
        mode = 'D';
      }
      runDefaultAnimations();
      break;
  }
}

/**
 * Get the last key pressed
 */
char getLastKey(void){
  char retKey = lastKey;
  lastKey = NO_KEY;
  return retKey;
}

/**
 * Update the OLED screen
 */
void displayUpdate(std::string message){
    oled->clearDisplay();
    oled->setCursor(0, 0);
    oled->setTextSize(2);
    oled->println(" -DCZia26-");
    oled->setTextSize(1);
    oled->println(message.c_str());
    oled->display();
}

/**
 * Run the default animation - low intensity rainbow
 */
void runDefaultAnimations(void){
  //Default Animation Loop
  if (animations.IsAnimating()) {
    // The normal loop just needs these two to run the active animations
    animations.UpdateAnimations();
    strip.Show();
  } else {
    // No animation runnning, start some
    FadeInFadeOutRinseRepeat(.05f); // 0.0 = black, 0.25 is normal, 0.5 is bright
  }
}

void displayBand(int band, int dsize){
  // Draw the max number of lines for OLED EQ display
  if (band == 7) {oled->drawFastHLine(18*6,0,14,1);}
  for (int s = 0; s <= dsize; s=s+2){oled->drawFastHLine(18*band,64-s,14,1);}
  if (dsize > peak[band]) {peak[band] = dsize;}
}

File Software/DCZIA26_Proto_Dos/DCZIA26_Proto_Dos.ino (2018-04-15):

#include <Adafruit_NeoPixel.h>
#ifdef __AVR__
  #include <avr/power.h>
#endif

#define NEOPIXEL_PIN 26

// Parameter 1 = number of pixels in strip
// Parameter 2 = Arduino pin number (most are valid)
// Parameter 3 = pixel type flags, add together as needed:
//   NEO_KHZ800  800 KHz bitstream (most NeoPixel products w/WS2812 LEDs)
//   NEO_KHZ400  400 KHz (classic 'v1' (not v2) FLORA pixels, WS2811 drivers)
//   NEO_GRB     Pixels are wired for GRB bitstream (most NeoPixel products)
//   NEO_RGB     Pixels are wired for RGB bitstream (v1 FLORA pixels, not v2)
//   NEO_RGBW    Pixels are wired for RGBW bitstream (NeoPixel RGBW products)
//Adafruit_NeoPixel strip = Adafruit_NeoPixel(60, NEOPIXEL_PIN, NEO_GRB + NEO_KHZ800); //Gradual Fade
Adafruit_NeoPixel strip = Adafruit_NeoPixel(40, NEOPIXEL_PIN, NEO_GRB + NEO_KHZ800); //Rainbow Fade


// IMPORTANT: To reduce NeoPixel burnout risk, add 1000 uF capacitor across
// pixel power leads, add 300 - 500 Ohm resistor on first pixel's data input
// and minimize distance between Arduino and first pixel.  Avoid connecting
// on a live circuit...if you must, connect GND first.

void setup() {
  strip.begin();
  strip.show(); // Initialize all pixels to 'off'
}

void loop() {
  // Some example procedures showing how to display to the pixels:
  //rainbow(60);
  rainbowCycle(32);

}



//////////////////////
// Color Functions // 
/////////////////////

// Fill the dots one after the other with a color
void colorWipe(uint32_t c, uint8_t wait) {
  for(uint16_t i=0; i<strip.numPixels(); i++) {
    strip.setPixelColor(i, c);
    strip.show();
    delay(wait);
  }
}

void rainbow(uint8_t wait) {
  uint16_t i, j;

  for(j=0; j<256; j++) {
    for(i=0; i<strip.numPixels(); i++) {
      strip.setPixelColor(i, Wheel((i+j) & 255));
    }
    strip.show();
    delay(wait);
  }
}

// Slightly different, this makes the rainbow equally distributed throughout
void rainbowCycle(uint8_t wait) {
  uint16_t i, j;

  for(j=0; j<256*5; j++) { // 5 cycles of all colors on wheel
    for(i=0; i< strip.numPixels(); i++) {
      strip.setPixelColor(i, Wheel(((i * 256 / strip.numPixels()) + j) & 255));
    }
    strip.show();
    delay(wait);
  }
}

//Theatre-style crawling lights.
void theaterChase(uint32_t c, uint8_t wait) {
  for (int j=0; j<10; j++) {  //do 10 cycles of chasing
    for (int q=0; q < 3; q++) {
      for (uint16_t i=0; i < strip.numPixels(); i=i+3) {
        strip.setPixelColor(i+q, c);    //turn every third pixel on
      }
      strip.show();

      delay(wait);

      for (uint16_t i=0; i < strip.numPixels(); i=i+3) {
        strip.setPixelColor(i+q, 0);        //turn every third pixel off
      }
    }
  }
}

//Theatre-style crawling lights with rainbow effect
void theaterChaseRainbow(uint8_t wait) {
  for (int j=0; j < 256; j++) {     // cycle all 256 colors in the wheel
    for (int q=0; q < 3; q++) {
      for (uint16_t i=0; i < strip.numPixels(); i=i+3) {
        strip.setPixelColor(i+q, Wheel( (i+j) % 255));    //turn every third pixel on
      }
      strip.show();

      delay(wait);

      for (uint16_t i=0; i < strip.numPixels(); i=i+3) {
        strip.setPixelColor(i+q, 0);        //turn every third pixel off
      }
    }
  }
}

// Input a value 0 to 255 to get a color value.
// The colours are a transition r - g - b - back to r.
uint32_t Wheel(byte WheelPos) {
  WheelPos = 255 - WheelPos;
  if(WheelPos < 85) {
    return strip.Color(255 - WheelPos * 3, 0, WheelPos * 3);
  }
  if(WheelPos < 170) {
    WheelPos -= 85;
    return strip.Color(0, WheelPos * 3, 255 - WheelPos * 3);
  }
  WheelPos -= 170;
  return strip.Color(WheelPos * 3, 255 - WheelPos * 3, 0);
}

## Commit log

2018-01-01 Create DCZIA26_SKETCH1
    Sketch has a bouncing zia, example code from the internet, and a sample scroll buffer.
2018-01-28 Added Keycap STL File
    Here is the keycap that i modded from the opensource Adafruit cherry mx designs. I call this custom profile "DCZSA" since it was roughly based off a "DSA" profile cap with the top chopped off to aid 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
    [Cherry_MX_Keycap_Flat_Top_WNA.stl]
2018-03-29 Reorganized files Added the design files for the DC26 proto boards
    [Button.sldprt, Cherry_MX_Keycap_Flat_Top_WNA.stl, ESP32.sldprt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]
2018-04-15 Fixed badge light issue for test code
    [DCZIA26_Proto_Dos.ino]
2018-04-22 initial commit of tri-function app (oled, led, keypad)
2018-04-22 fixed pin numbers for keypad rows/cols
2018-04-24 fixed col0 pin, increased keymap size to 16
    [Keypad.h]
2018-04-25 switch to drive rows (scan cols) so we can use internal pullups
2018-05-07 fancier oled message during main_menu led test
2018-06-07 added function to set LED by address (LED_RxCx) similar to key address (KEY_RxCx)
2018-06-13 Adding design files for the KeyGridBadge
    [Button.sldprt, ESP32.sldprt, Header 1 Pin.SLDPRT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]
2018-06-17 Updated board to include switching regulator
    [KeyGridBadge-B.Cu.gbl, KeyGridBadge-B.Mask.gbs, KeyGridBadge-B.Paste.gbp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]
2018-06-26 Adding pdf versions of schematic and layers
    [KeyGridBadge.drl]
2018-06-26 Adding Seeed logo to the board
    [KeyGridBadge-B.Cu.gbl, KeyGridBadge-B.Mask.gbs, KeyGridBadge-B.Paste.gbp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]
2018-06-26 Adding a schottky diode to the boost reg
    [KeyGridBadge-B.Cu.gbl, KeyGridBadge-B.Mask.gbs, KeyGridBadge-B.Paste.gbp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]
2018-06-29 Final board design as sent to fab for assembly Fixed the SD card footprint to match Seeed's part
    [KeyGridBadge-B.Cu.gbl, KeyGridBadge-B.Mask.gbs, KeyGridBadge-B.Paste.gbp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]
2018-07-17 Added BLE Support for #badgelife communications.
    Updated to include manufacturer id and correct appearance.
    Updates to proto-dos sketch so it compiles and works with WeMos dev board.
    Updates to README.md to include some setup instructions.
    Cleaned up rando commented code.
    [dczia26_ble.cpp, dczia26_led.cpp]
2018-07-28 Front & Back of Business Card
    Feel free to comment. I still have time to make any changes and print before DC
2018-08-05 Switched up OLED library to use adafruit's SSD1306 instead of ThingPulse.
    Cleaned up most references to old SSD1306 object, modified welcome code.
2018-08-06 Updated some led stuff
2018-08-06 Update keymapping on badge
    Why:
    * Top left button on badge thinks it is bottom left
    How:
    * Change keypad to be on Column/Row order
    * Change LEDs to map to new ordering
2018-08-08 fix build from bad merge.
    [dczia26_final.ino]
2018-12-04 Added n-key rollover to the pixel picker Changed menu mode to be a hold of the lower right key Changed key scanning to happen in an interrupt in prep for HID minibadge support Added escapes for light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
    [Keypad.cpp, dczia26_ble.cpp, dczia26_final.ino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]
2019-06-02 Audio module fully unlocked! (#16)
    * Adding support for audio module
    * Adding latest changes before breaking everything
    * Adding semi-beat driven LED flashing
    * Final version of EQ tested. 69 Days to DEF CON 27!
    * Real final version of EQ w/ bugs fixed. 67 Days to DEF C☺N 27!
    Work done by @Aask42 !
    [dczia26_final.ino, dczia26_led.cpp, dczia26_led.h]
